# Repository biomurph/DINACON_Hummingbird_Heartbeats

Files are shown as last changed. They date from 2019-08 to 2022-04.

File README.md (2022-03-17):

# Humming Bird Pulse Sensor

Hi.
This project is also on [Hackaday.io](https://hackaday.io/project/184261-hummingbird-heartbeats)

Adding files as they become publishable (read: workish)

## Basic Shape
What you have here is a Teensy 3.6 that reads 5 analog inputs at a very high rate and stores the data to SD card. 

-	Sensors
	- Pulse Sensor 2x
	- Analog Accelerometer

The signal of interest is likely in the hundreds of hertz. Here's a ball park:

	Hummingbird Heart Rate 800 Beats Per Minute (BPM)
	BPM = 60 Seconds / Inter-beat Interval (IBI)

the IBI value is the time between beats. the IBI associated with a heart rate of 800 BPM is 75 milliseconds (0.075 Seconds). That 800 BPM number I just pulled out of the air. It could be faster, based on the liturature. So we need a high sample rate. 

I'm starting with a Teensy 3.6 and the [ExFatLogger.ino](https://github.com/greiman/SdFat/tree/master/examples/ExFatLogger) example to get high speed SD card writing. The basic Arduino code is [there](https://github.com/biomurph/DINACON_Hummingbird_Heartbeats/tree/2022/2022/Arduino/humm_beat_sensor_01).

## Hardware
The device simply will not work if SD card is not installed! Unplug device, install SD card, plug in device.

### Pulse Sensors
The Pulse Sensors are 'sealed' with nail polish on the back. If you need to re-apply any sealant, you must use care so that the paint or sealant you use does not creep or wick around the LED in the middle of the board! Super important.
The RED Pulse Sensor is the first data column, the BLUE Pulse Sensor is the second data column.
On the front, they have a clear vinyl sticker. There are replacement stickers in the kit if you need to replace one.
### Accelerometer
The Accelerometer is also 'conformally coated' on the circuit side with nail polish. The accelerometer X, Y, and Z axis are the 3rd, 4th, and 5th data columns. See below for sample data. It's the [ADXL-335](https://www.adafruit.com/product/163).

This is the force axis orientation.

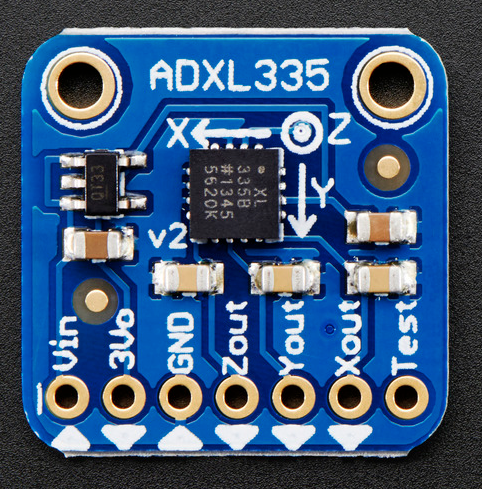
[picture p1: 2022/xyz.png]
xyz


### Push Button
The push button can be used to initiate a recording session. All it does is initiate. Recordings are timed. See below.
### Coin Battery
There is a coin battery holder that you can use to add a coin battery. The coin battery, when installed, will help the 
## User Guide

The interface allows you to create, access, and manipulate binary files. Sensor data is recorded to the SD card in a binary format to facilitate high speed logging.

Hardware is powered via USB, and requires a connected Terminal or Data Visualizer to begin operation.  When you plug in the USB *without Terminal or Data Visualizer* the BLUE LED will be steady on. Once the port is connected, the BLUE LED will pulse/fade nicely saying it is ready. Set your serial port to 250000 baud. These are the keyboard commands that you can use to control the device:

	type: 
	b - open existing bin file
	c - convert bin file to csv file (DON'T TRY TO CONVERT A CSV FILE!)
	l - list files
	p - print opened bin file data to Serial (DON'T TRY TO PRINT A CSV FILE!)
	r - record data
	t - test without logging
	? - print this message
	type a number to set record duration
		 1 - 5 seconds
		 2 - 10 seconds
		 3 - 15 seconds
		 4 - 20 seconds

It is recommended to follow a specific series of steps to use the interface efficiently. Though it is not possible to screw it up really bad, it can be confusing without this guide. Here are the steps for success:
### RECORDING DATA

1. Insert a micro SD card that is formatted as ExFat (super important)
2. Open Arduino IDE
3. Plug into USB computer
4. Select the port from the Tools > Port drop down menu
5. Open up the Arduino Serial Plotter (Command + Shift + L)
6. Make sure your baud rate is set to 250000
7. In the 'data to send' window, you can use the command set to control the device.
8. Start by sending `t` to begin streaming data to the terminal for viewing and verification
9. When you want to do any recording, send `r` or press the red button to record. The data stream will halt while recording
10. When record time is up, you need to send `t` again to bring back the data stream
11. Repeat steps to visualize and record as you like.

**NOTE: There are messages that are sent before and after the data stream, so you might see 'glitching' at these transient times**

***needs a pic of the Arduino Plotter with notes***

### RETREIVING DATA

1. Close the Serial Plotter, if it is open
2. Open the Serial Monitor (Command + Shift + M)
3. Send `l` to list the files that are on the disk
4. Send `b` to request to open a binary file
5. Type in the name of the binary file exactly: `Humm_01.bin` for example
6. Once the file is open, send `c` to convert it into a `.csv` file
7. The new `.csv` file will now be listed when you send `l`
8. Rinse, repeat

This code is super duper simple. There's no command to close a file, for example. Just trust that when you open a new file or start recording you will be closing the old one. When you've converted all of the files that you want to, unplug the device and remove the SD card. I recommend using the spudger included to make SD card removal easy. If you have long nails, that works too.  Use the included SD card reader dongle to retrieve the desired CSV files.
After copying the data you want off the micro SD, you can clear the disk by moving all the files into your trash.

**Make sure to empty your trash on the computer before un-mounting the disk to properly delete files from the disk**

# Data
Data is initially stored in .bin files. You need to manually convert them to .csv files for further processing.
There are two file types and 4 file size options. The Serial Monitor will give you data on all of this when you list files or record with the monitor open. here are examples of file sizes in bytes for different record times

Record Duration | BIN file size | CSV file size
:--------------:|:-------------:|:------------:
5 Seconds  |  100,502  |   280,524   |
10 Seconds |  200,502  |   564,669   |
15 Seconds |  300,502  |   847,828   |
20 Seconds |  400,502  |   1,125,782   |

The CSV data file will look like this

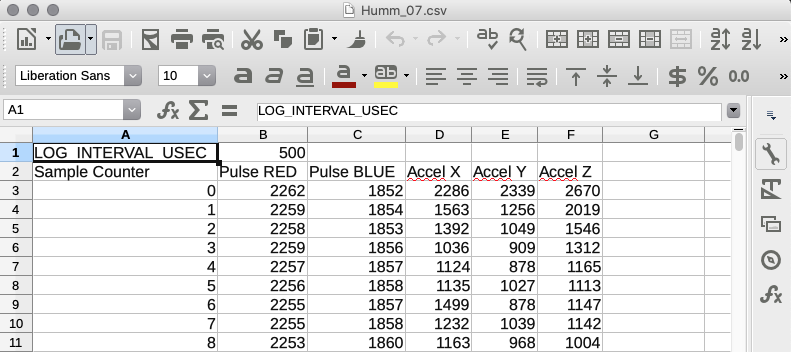
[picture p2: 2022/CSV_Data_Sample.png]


The first column is a simple sample counter. It is only a byte, and it will roll over to `0` after it hits `255`. I've limited it's maximum size to make the Serial Plotter more manageable. The data is raw, and it's generated by a 12 bit ADC, so the range is from `0` to `4095`. All of the sensors will idle at approx 1/2 of the analog range. for the accelerometer values, the ADC value is directly linearly scalable to gs. `0` counts is -3.0g and `4095` counts is +3.0g
	
## Serial Plotter
Arduino Serial Plotter is pretty simple, and it auto ranges. The maximum range of the data of interest is 4095. If you see a spike that is much higher than that (auto ranging), you will need to wait for the spike to travel across the screen.

You'll likely want to switch between Serial Monitor and Serial Plotter, so use the key commands. The Serial Monitor has a text field at the top to send commands, and the Plotter has a text field on the bottom.

`COMMAND + w` to close an open window

`COMMAND + SHIFT + L` open plotter window

`COMMAND + SHIFT + M` open monitor window

I'm holding my fingers on the two Pulse Sensors, and the accelerometer is laying flat on my desk in the image below. The Z axis is registering 1g due to gravity, and the dark and light blue lines in the center are the other axis registering 0g-ish. If the Accelerometer is held flat against the bird, then the Z axis could register expansion due to respiration`?`

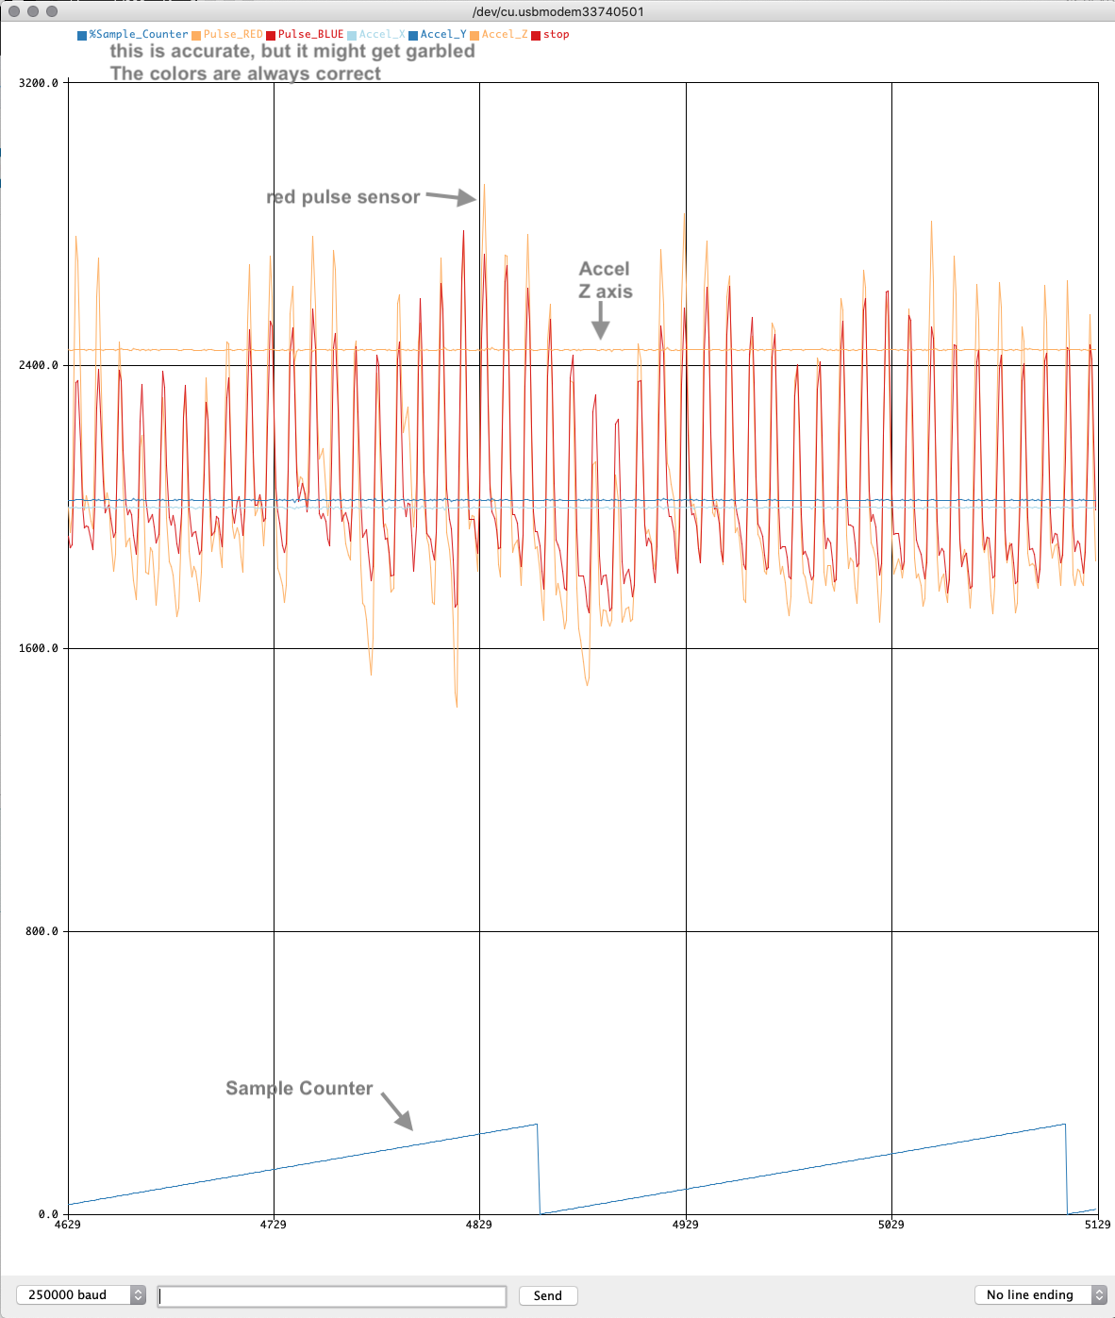
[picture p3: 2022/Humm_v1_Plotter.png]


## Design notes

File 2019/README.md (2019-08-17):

# DINACON Humming Bird Pulse Sensor

Helping [Jay Falk](https://www.birdmorph.com/) to measure Humming Bird Heartbeats with [Pulse Sensor](www.pulsesensor.com)
Jay is a scientist who studies hummingbirds in Gamboa, Panama. It was recently discovered that hummingbirds (some, not all?) can vocalize, that is make sounds, up to 15KHz. At the same time, it is generally believed that birds can only hear sounds up to 8KHz. Jay wants to know if hummingbirds can hear in the higher registers that they make sounds in. His thought is that maybe the birds heart rate changes when they hear another bird call, and that if he can measure heart rate this might be a way to prove that they can hear in the higher registers.

I have been making and selling Pulse Sensor, an optical heart rate monitor, since 2012. There happen to be a couple of Pulse Sensors at the Dinalab, and so very soon after I arrived at Dinacon, I got together with Jay to try and see if we could find a hummingbird heart beat with Pulse Sensor. 

The Pulse Sensor uses the principal of [Photoplethysmography](https://en.wikipedia.org/wiki/Photoplethysmogram) to measure heart beats. Here is a page that discribes the [features](https://www.researchgate.net/figure/A-typical-waveform-of-the-PPG-and-its-characteristic-parameters-whereas-the-amplitude-of_fig9_230587653) of the waveform that we're looking for.

Hummigbirds have a couple of 'bald spots' where hair doen't grow. Typically, most birds don't have feathers on their lower abdomen in order to make a good connection to their eggs when incubating them. Also, Hummingbirds have no feathers right behind their crop on the back of their heads. We decided we would try both of those spots.

I used two Pulse Sensors. One was just a normal Pulse Sensor, and the other I modified by taking off the LED. I did this in order to test a reflective Pulse Sensor (the way they normally work) and a transmissive Pulse Sensor, where I used the light from the normal Pulse Sensor to send a signal through the body of the bird. It became clear very soon that the reflective Pulse Sensor was the best option.

We did se a signal when we placed the Pulse Sensor on the belly bald spot, however it was difficult to tell if we were reading the heartbeat or the breathing. Placing the Pulse Sensor on the bald spot behind the crop was much more successful, and we think we did see a heartbeat in that location.

Here is a [LINK](https://www.dropbox.com/sh/dgatqx7pgcjl1rp/AABGw35ZrMt65FjiA4dyHX-6a?dl=0) to a dropbox that has videos from the experiment.

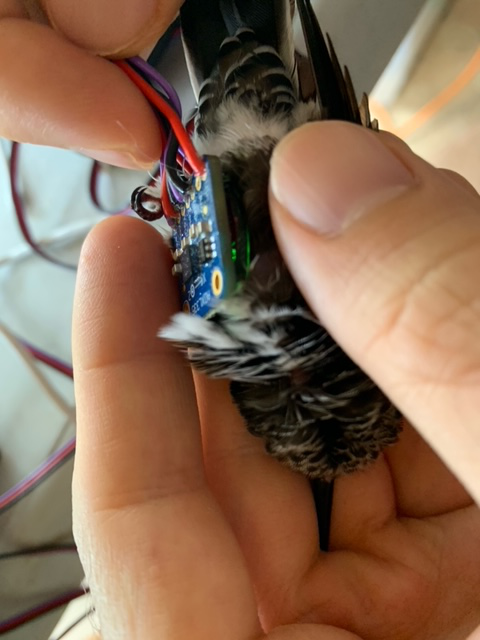
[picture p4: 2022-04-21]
2022/assets/PS-Acc_liveBird_4-22_01.jpeg

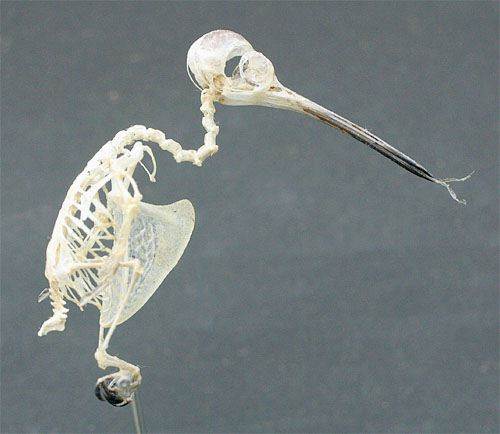
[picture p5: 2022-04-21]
2022/assets/HBskeleton.png

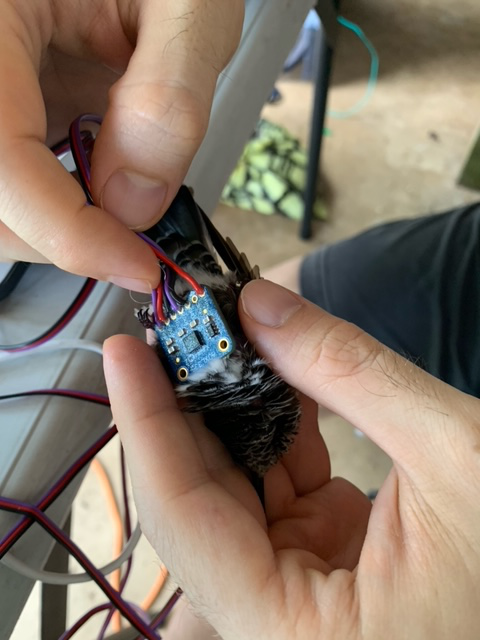
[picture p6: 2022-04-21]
2022/assets/PS-Acc_liveBird_4-22_00.jpeg

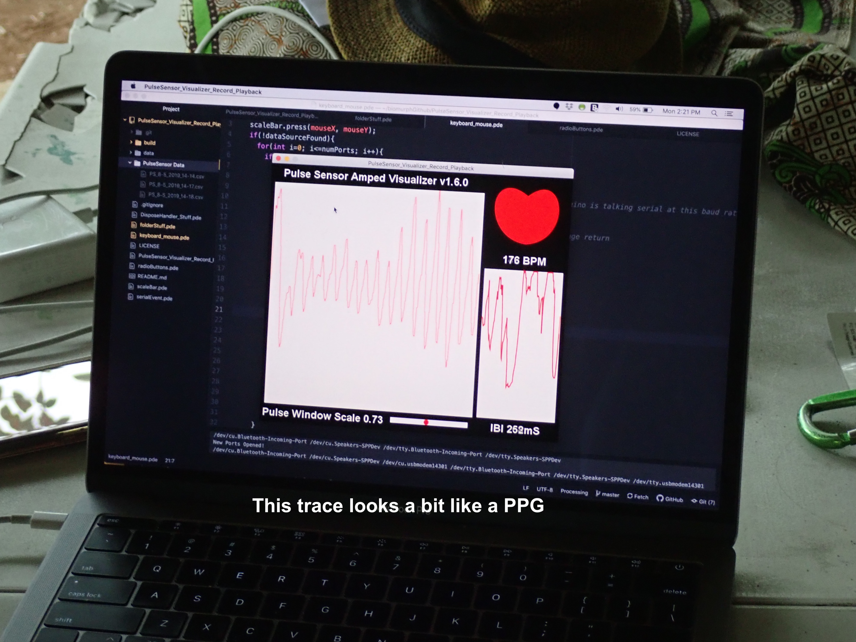
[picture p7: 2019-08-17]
2019/HummingBirdHeartbeats_18.JPG

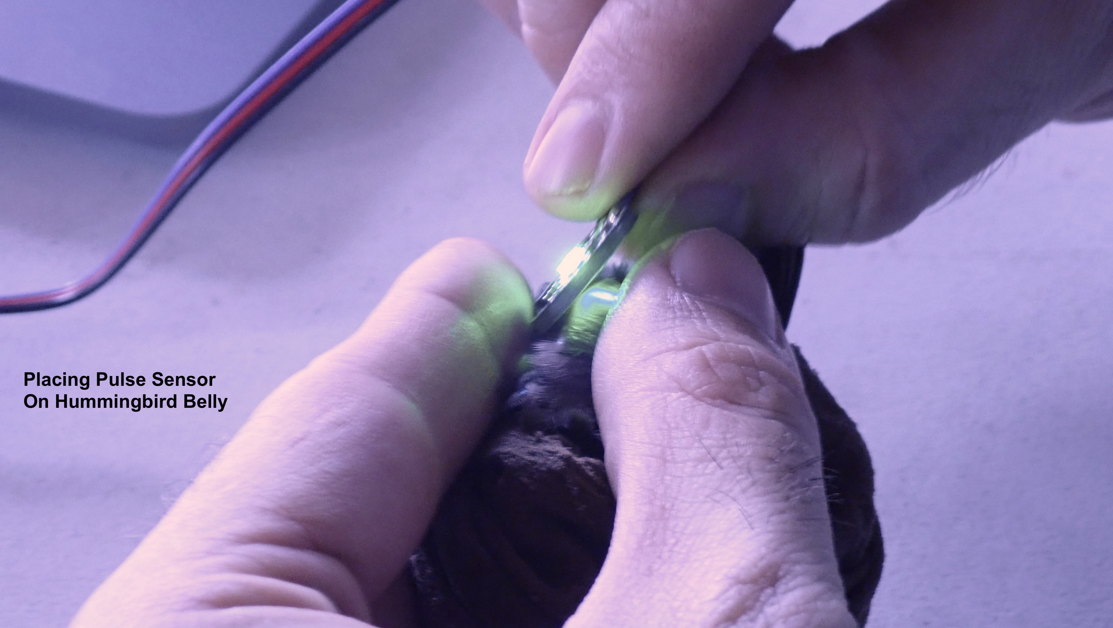
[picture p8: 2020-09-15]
2019/HummingBirdHeartbeats_06.JPG

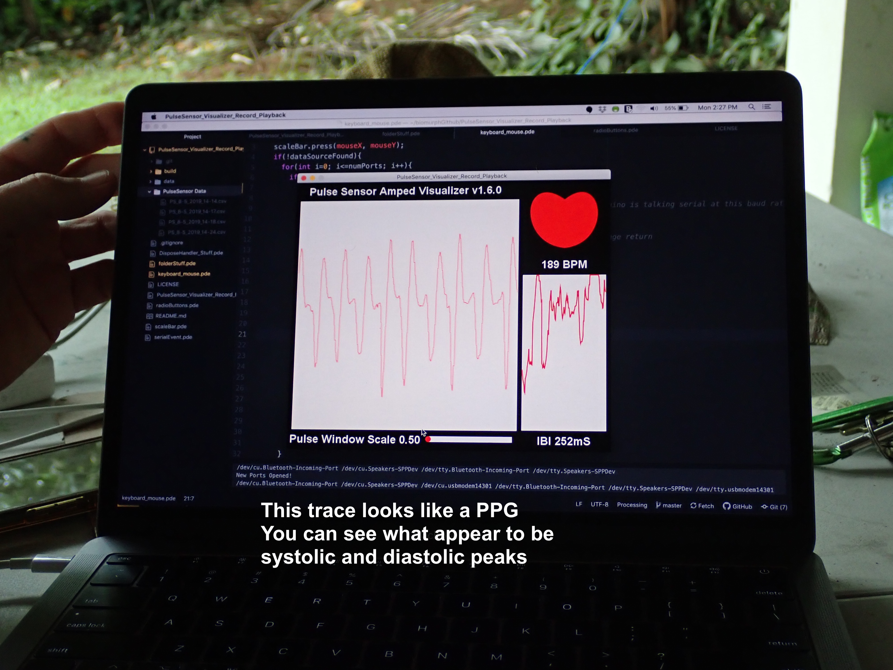
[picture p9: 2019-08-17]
2019/HummingBirdHeartbeats_21.JPG

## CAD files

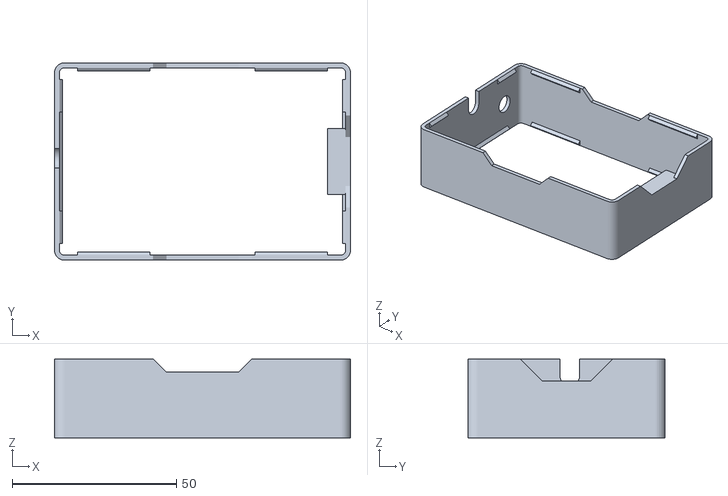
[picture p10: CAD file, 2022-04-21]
2022/Case Files/HummCase_01.stl
90.0 x 60.0 x 24.0

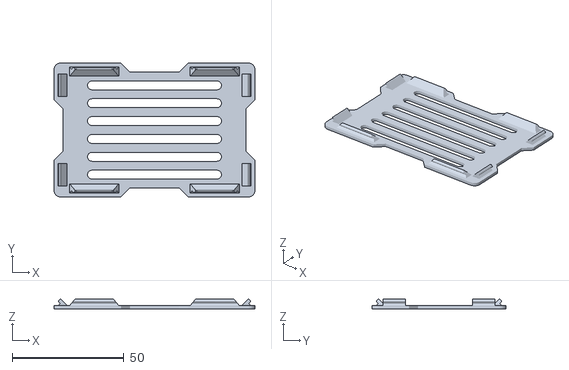
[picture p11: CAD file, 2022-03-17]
2022/Case Files/top-cover-halfsize.stl
90.0 x 60.0 x 4.35

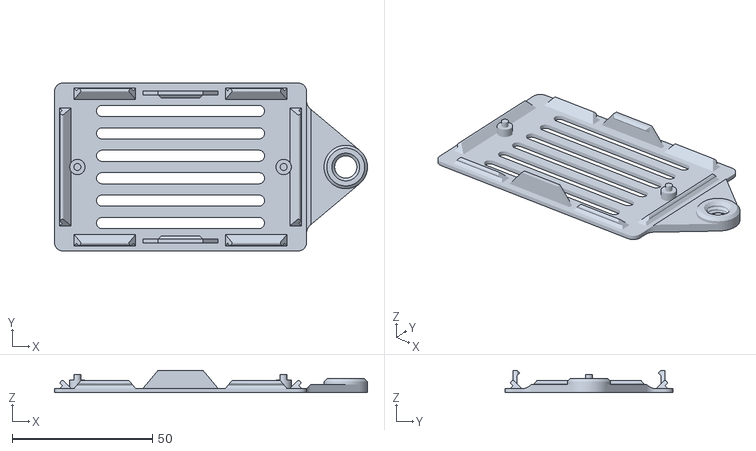
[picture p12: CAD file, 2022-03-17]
2022/Case Files/bottom-cover-tripod-halfsize.stl
111.8 x 60.0 x 8.00

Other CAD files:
2022/Case Files/case-halfsize.stl

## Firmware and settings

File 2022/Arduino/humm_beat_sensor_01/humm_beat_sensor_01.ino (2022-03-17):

/*
 *    this code targeted to Teensy 3.6
 *    use for baseline record capability and data retrieval
 *    set to highest ADC resolution
 *    
 */


// Example to demonstrate write latency for preallocated exFAT files.
// I suggest you write a PC program to convert very large bin files.
//
// The maximum data rate will depend on the quality of your SD
// the size of the FIFO, and using dedicated SPI.
// March, 2022: using ScanDisk EDGE 16GB micro with UHS 10

#include "SdFat.h"
#include "FreeStack.h"  // this is legacy from the example. not sure how useful.
#include "HummBird.h"
#include <TimeLib.h>  // used to time stamp files
#include <EEPROM.h>   // storing record duration.  or other things?


const uint64_t PREALLOCATE_SIZE  =  (uint64_t)PREALLOCATE_SIZE_MiB << 20;
// Max length of file name including zero byte.
#define FILE_NAME_DIM 40
// Max number of records to buffer while SD is busy.
const size_t FIFO_DIM = 512*FIFO_SIZE_SECTORS/sizeof(data_t);

#if SD_FAT_TYPE == 0
typedef SdFat sd_t;
typedef File file_t;
#elif SD_FAT_TYPE == 1
typedef SdFat32 sd_t;
typedef File32 file_t;
#elif SD_FAT_TYPE == 2
typedef SdExFat sd_t;
typedef ExFile file_t;
#elif SD_FAT_TYPE == 3
typedef SdFs sd_t;
typedef FsFile file_t;
#else  // SD_FAT_TYPE
#error Invalid SD_FAT_TYPE
#endif  // SD_FAT_TYPE

sd_t sd;

file_t binFile;
file_t csvFile;

#define error(s) sd.errorHalt(&Serial, F(s))
#define dbgAssert(e) ((e) ? (void)0 : error("assert " #e))

//------------------------------------------------------------------------------


//------------------------------------------------------------------------------
void testSensor() {
  const uint32_t interval = 50000;
  int32_t diff;
  data_t data;
  clearSerialInput();
  Serial.println(F("\nTesting - type any character to stop\n"));
  delay(500);
  printRecord(&Serial, nullptr);
  uint32_t m = micros();
  while (!isRunning) {
    m += interval;
    do {
      diff = m - micros();
      getButtonState();
      fadeLED(millis());
    } while (diff > 0);
    logRecord(&data, 0);
    printRecord(&Serial, &data);
    if(Serial.available()){ break; } 
  }
}
//------------------------------------------------------------------------------
void setup() {
  setSyncProvider(getTeensy3Time);
  if (ERROR_LED_PIN >= 0) {
    pinMode(ERROR_LED_PIN, OUTPUT);
    digitalWrite(ERROR_LED_PIN, HIGH);
  }
  pinMode(SAMPLE_CLK_PIN,OUTPUT); digitalWrite(SAMPLE_CLK_PIN,LOW);
  pinMode(ACCEL_TEST_PIN,OUTPUT); digitalWrite(ACCEL_TEST_PIN,LOW);
  sampleClockPinState = false;
  pinMode(BLU_LED,OUTPUT); analogWrite(BLU_LED,255);
  pinMode(RED_LED,OUTPUT); digitalWrite(RED_LED,LOW);
  pinMode(BUTTON_PIN,INPUT_PULLUP);
  buttonValue = lastButtonValue = digitalRead(BUTTON_PIN);
  analogReadResolution(12);  // crank up the bits
  
  Serial.begin(250000);
  // Wait for USB Serial
  while (!Serial) {
    yield();
  }
  delay(1000);
  Serial.println(F("Hummingbird Beats v1"));
//  Verify the RTC
  if (timeStatus()!= timeSet) {
      Serial.println("Unable to sync with the RTC");
    } else {
    Serial.println("RTC has set the system time");
  }
  
  FillStack();
#if !ENABLE_DEDICATED_SPI
  Serial.println(F(
    "\nFor best performance edit SdFatConfig.h\n"
    "and set ENABLE_DEDICATED_SPI nonzero"));
#endif  // !ENABLE_DEDICATED_SPI

  Serial.print(FIFO_DIM);
  Serial.println(F(" FIFO entries will be used."));

  // Initialize SD.
  if (!sd.begin(SD_CONFIG)) {
    sd.initErrorHalt(&Serial);
  }

  FsDateTime::setCallback(dateTime);

  recordDuration = setRecordDuration(STARTUP_DURATION);
  lastFadeTime = millis();
  printUnusedStack();
  clearSerialInput();
  printControl();
}

  
//------------------------------------------------------------------------------
void loop() {
  // Read any Serial data.
  fadeLED(millis());
  getButtonState();
  serialCheck();
  if(isRunning){
    createBinFile(); logData();
    // logData jumps to a loop that waits for Serial or a time out to break
    isRunning = false;
  }
  if(freeRunningTest){
    testSensor();
    freeRunningTest = false;
  }
}

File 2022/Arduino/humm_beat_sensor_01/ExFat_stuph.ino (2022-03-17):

//==============================================================================


// Replace logRecord(), printRecord(), and ExFatLogger.h for your sensors.
int logRecord(data_t* data, uint16_t overrun) {
  if (overrun) {
    // Add one since this record has no adc data. Could add overrun field.
    overrun++;
    data->adc[0] = 0X8000 | overrun;
    return -1;
  } else {
    timeIn = micros();
    for(size_t i=0; i<ADC_COUNT; i++) {
      data->adc[i] = analogRead(i);
    }
  }
  timeOut = micros() - timeIn;
  return timeOut;
}
//------------------------------------------------------------------------------
void printRecord(Print* pr, data_t* data) {
  static uint8_t nr = 0;
  if (!data) {
    pr->print(F("%LOG_INTERVAL_USEC,"));
    pr->println(LOG_INTERVAL_USEC);
    pr->print(F("%FILE_NAME,")); pr->println(binName);
    pr->print(F("%RECORD_DURATION")); pr->println(recordDuration/1000);
    pr->print(F("%Sample_Counter"));
    for (size_t i = 0; i < ADC_COUNT; i++) {
      pr->print(getChannelString(i));
    }
    pr->println();
    nr = 0;
    return;
  }
  if (data->adc[0] & 0x8000) {
    uint16_t n = data->adc[0] & 0x7FFF;
    nr += n;
    pr->print(F("-1,"));
    pr->print(n);
    pr->println(F(",overuns"));
  } else {
    pr->print(nr++);
    for (size_t i = 0; i < ADC_COUNT; i++) {
      pr->write(',');
      pr->print(data->adc[i]);
    }
    pr->println();
  }
}

//==============================================================================
String getChannelString(int i){
  String s = "";
  switch(i){
    case 0:
      s = F(",Pulse_RED");
      break;
    case 1:
      s = F(",Pulse_BLUE");
      break;
    case 2:
      s = F(",Accel_X");
      break;
    case 3:
      s = F(",Accel_Y");
      break;
    case 4:
      s = F(",Accel_Z");
      break;
    default: 
      s = F(",Channel Name Error");
      break;
  }
  return s;
}

//==============================================================================

void openBinFile() {
  char name[FILE_NAME_DIM];
  clearSerialInput();
  Serial.println(F("Enter file name"));
  if (!serialReadLine(name, sizeof(name))) {
    return;
  }
  if (!sd.exists(name)) {
    Serial.println(name);
    Serial.println(F("File does not exist"));
    return;
  }
  binFile.close();
  if (!binFile.open(name, O_RDONLY)) {
    Serial.println(name);
    Serial.println(F("open failed"));
    return;
  }
  Serial.print(name);
  Serial.println(F("\tFile opened"));
}

//-------------------------------------------------------------------------------
void logData() {
  int32_t delta;  // Jitter in log time.
  int32_t maxDelta = 0;
  uint32_t maxLogMicros = 0;
  uint32_t maxWriteMicros = 0;
  uint32_t analogReadMicros;
  uint32_t maxAnalogReadMicros = 0;
  size_t maxFifoUse = 0;
  size_t fifoCount = 0;
  size_t fifoHead = 0;
  size_t fifoTail = 0;
  uint16_t overrun = 0;
  uint16_t maxOverrun = 0;
  uint32_t totalOverrun = 0;
  uint32_t fifoBuf[128*FIFO_SIZE_SECTORS];
  data_t* fifoData = (data_t*)fifoBuf;

  // Write dummy sector to start multi-block write.
  dbgAssert(sizeof(fifoBuf) >= 512);
  memset(fifoBuf, 0, sizeof(fifoBuf));
  if (binFile.write(fifoBuf, 512) != 512) {
    error("write first sector failed");
  }
  clearSerialInput();
  Serial.println(F("Type any character to stop"));

  // Wait until SD is not busy.
  while (sd.card()->isBusy()) {}

  // Start time for log file.
  uint32_t m = millis();

  // Time to log next record.
  uint32_t logTime = micros();
  // Here's where it locks up
  while (true) {
    digitalWrite(RED_LED,HIGH);
    analogWrite(BLU_LED,0);
    // Time for next data record.
    logTime += LOG_INTERVAL_USEC;
    sampleClockPinState = !sampleClockPinState;
    digitalWrite(SAMPLE_CLK_PIN,sampleClockPinState);
    // Wait until time to log data.
    delta = micros() - logTime;
    if (delta > 0) {
      Serial.print(F("delta: "));
      Serial.println(delta);
      error("Rate too fast");
    }
    while (delta < 0) {   // this is where the delay happens
      delta = micros() - logTime;
    }

    if (fifoCount < FIFO_DIM) {
      uint32_t m = micros();
      analogReadMicros = logRecord(fifoData + fifoHead, overrun);
      if(analogReadMicros > maxAnalogReadMicros){ maxAnalogReadMicros = analogReadMicros; }
      m = micros() - m;
      if (m > maxLogMicros) {
        maxLogMicros = m;
      }
      fifoHead = fifoHead < (FIFO_DIM - 1) ? fifoHead + 1 : 0;
      fifoCount++;
      if (overrun) {
        if (overrun > maxOverrun) {
          maxOverrun = overrun;
        }
        overrun = 0;
      }
    } else {
      totalOverrun++;
      overrun++;
      if (overrun > 0XFFF) {
        error("too many overruns");
      }
      if (ERROR_LED_PIN >= 0) {
        digitalWrite(ERROR_LED_PIN, HIGH);
      }
    }
    // Save max jitter.
    if (delta > maxDelta) {
      maxDelta = delta;
    }
    // Write data if SD is not busy.
    if (!sd.card()->isBusy()) {
      size_t nw = fifoHead > fifoTail ? fifoCount : FIFO_DIM - fifoTail;
      // Limit write time by not writing more than 512 bytes.
      const size_t MAX_WRITE = 512/sizeof(data_t);
      if (nw > MAX_WRITE) nw = MAX_WRITE;
      size_t nb = nw*sizeof(data_t);
      uint32_t usec = micros();
      if (nb != binFile.write(fifoData + fifoTail, nb)) {
        error("write binFile failed");
      }
      usec = micros() - usec;
      if (usec > maxWriteMicros) {
        maxWriteMicros = usec;
      }
      fifoTail = (fifoTail + nw) < FIFO_DIM ? fifoTail + nw : 0;
      if (fifoCount > maxFifoUse) {
        maxFifoUse = fifoCount;
      }
      fifoCount -= nw;
      // escape routines
      // vvvvvvvvvvvvvvv
      if (Serial.available()) { break; }
////     if (getButtonState() != RECORD_ON) { break; } // DO NOT USE needs reliable fast switch to impliment 
// recordDuration set in EEPROM or update via serial port
      if (millis() - m >= recordDuration) { break; }
      // ^^^^^^^^^^^^^^^
      // escape routines
    }
  }
  Serial.print(F("\nLog time Seconds: ")); Serial.println(0.001*(millis() - m));
  Serial.print(F("File size: "));
  Serial.print((uint32_t)binFile.fileSize()/1000); Serial.println(F(" Kbytes"));
  Serial.print(F("totalOverrun: ")); Serial.println(totalOverrun);
  Serial.print(F("FIFO_DIM: ")); Serial.println(FIFO_DIM);
  Serial.print(F("maxFifoUse: ")); Serial.println(maxFifoUse);
  Serial.print(F("maxLogMicros: ")); Serial.println(maxLogMicros);
  Serial.print(F("maxWriteMicros: ")); Serial.println(maxWriteMicros);
  Serial.print(F("Log interval micros: ")); Serial.println(LOG_INTERVAL_USEC);
  Serial.print(F("maxDelta micros: ")); Serial.println(maxDelta);
  Serial.print(F("maxAnalogReadMicros: ")); Serial.println(maxAnalogReadMicros);
  binFile.truncate();
  binFile.sync();
}
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

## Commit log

2022-03-08 new branch with latest code dev
    [bottom-cover-halfsize.stl, bottom-cover-slots-halfsize.stl, bottom-cover-tripod-halfsize.stl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]
2022-03-13 brought back the RTC components
    Files are time stamped when they are created while connected to the computorb. Option for external coin battery is available via coin battery holder. Only use 3V lithium, please.
2022-03-14 updating readme
    polishing this thing
    [bottom-cover-halfsize.stl, bottom-cover-slots-halfsize.stl, case-halfsize.stl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]
2022-03-17 bug fixes and readme update
    [ExFat_stuph.ino, HummBird.h, humm_beat_sensor_01.ino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]
2022-04-21 data and assets
    [HummCase_01.stl]
